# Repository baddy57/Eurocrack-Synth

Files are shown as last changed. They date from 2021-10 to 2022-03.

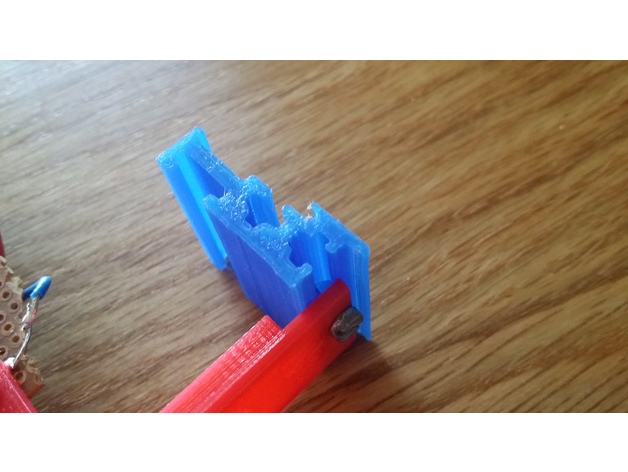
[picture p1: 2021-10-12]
3D PARTS/RACK16/trash/Parametric_Eurorack_Rail2/images/8c8c8380b167ee0547331ad15cff7e31_preview_featured.jpg

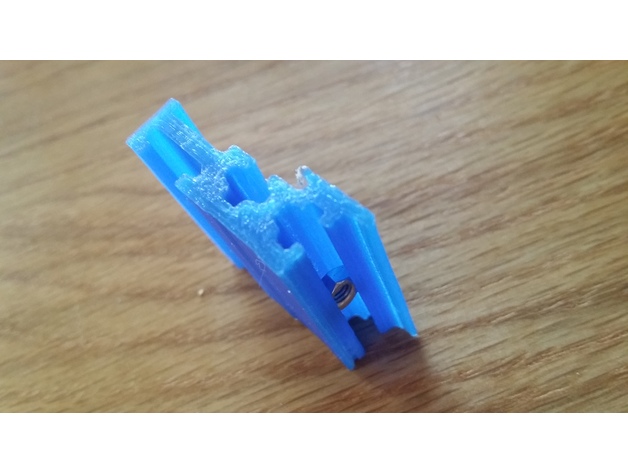
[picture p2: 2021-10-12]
3D PARTS/RACK16/trash/Parametric_Eurorack_Rail2/images/5f590f1a4b3af3753e3ca944733ad141_preview_featured.jpg

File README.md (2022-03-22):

# Eurocrack-Synth
inspired by https://github.com/mattybrad/polymod

this is my clone of an eurorack modular synthesizer.<br>
it works based on a teensy board and uses paul stoffregen's audio library and other arduino libraries

basically there are a bunch of cascaded multiplexers, which are used to get as many things as possible connected to the board.<br>
up to 4 cases can be connected with db25 cables to the main box, and each of them can have up to 16 modules connected via 16pin flat cables.<br>
each one of these 64 slots has an address, corresponding to the multiplexers selectors values used to reach them.<br>
every module has an unique id (set via dip switches) and when the teensy is turned on, it reads this id to understand which modules are connected and where.<br>
modules can have up to 8 3.5mm sockets that can send signals to other modules and up to 24 (small pcb) or 56 (big pcb) among potentiometers, switches, buttons, faders and 3.5mm sockets for receiving signals.
(the actual number of the inputs in lower because both input and outputs sockets use two pins)

any output socket can be connected to multiple inputs using 3.5mm mono jacks and splitters.<br>
the signal that flows in these cables is not an audio signal, but just a digital signal sent from the outputs, that, if received by any inputs, lets the code know that an audioconnection object must be created.

similarities to real eurorack synths:<br>
	module size, which is 128.5 x 5.08*n mm<br>    .
	m3 screws used to attach the modules to the rack<br>
	3.5mm mono jacks<br>
	fpc16 cables<br>

other features: <br>
	analog audio in/out, thanks to the teensy audio board <br>
	usb audio in/out <br>
	midi in/out <br>
	usb midi in/out <br>
	a touch screen display (used mainly for debugging purposes at the moment) <br>
	polyphony<br>
	of course, rgb leds (i still need to fix them though)

special thanks to:<br>
	Paul Stoffregen and anybody who has worked on the audio library <br>
	everyone on the pjrc forum<br>
	youtube channel notes and volts<br>
	again mattybrad for sharing his code<br>

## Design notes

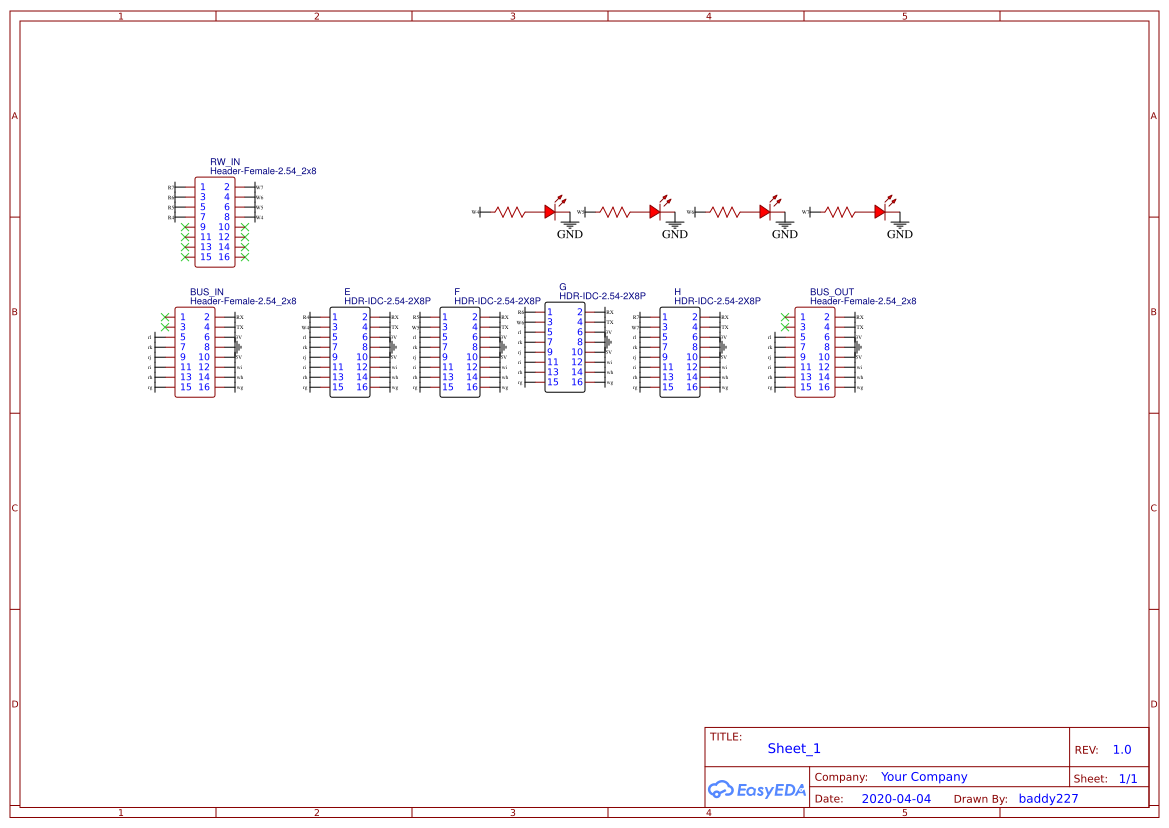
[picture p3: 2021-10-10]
PCB/Project_rack16_B_2021-10-10_22-06-08/1d647eb44f6a4349aa5675ee98e57c5a.png

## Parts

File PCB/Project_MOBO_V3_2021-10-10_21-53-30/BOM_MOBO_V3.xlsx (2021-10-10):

ID | Name | Designator | Footprint | Quantity
1 | 10uF | C1 | CAP-TH_BD5.0-P2.5-D0.5-FD | 1
2 | 1N4448 | D1 | DO-35 | 1
3 | HDR-IDC-2.54-2X8P | P1 | IDC-TH_16P-P2.54_C3406 | 1
4 | USB-B-Female-TH_C46393 | USB_B | USB-B_4PIN-FEMALE_BF90 | 1
5 | USB-AF-90-13.6X14.4-H6.95 | USB_A | USB-A-TH_C42628 | 1
6 | Header-Male-2.54_1x3 | RGB0 | HDR-TH_3P-P2.54-V | 1
7 | Female header 2.54-1*14P | T0,T1 | HDR-TH_14P-P2.54-V | 2
8 | USB_H | H3 | HDR-F-2.54_1X5 | 1
9 | HDR-IDC-2.54-2X13P | DB25_3,DB25_1,DB25_2,DB25_0 | HDR-IDC-2.54-2X13P | 4
10 | LED-TH-3mm_R | LED1 | LED-TH_BD3.0_RED | 1
11 | 6N138 | 6N138 | DIP-8_L9.8-W6.6-P2.54-LS7.6-BL | 1
12 | 47 | R3,R2 | AXIAL-0.3 | 2
13 | 220 | R1 | AXIAL-0.3 | 1
14 | 4051 | WRITE,READ | DIP-16_L20.0-W6.4-P2.54-LS7.6-BL | 2
15 | 1k | R4 | R_AXIAL-0.3 | 1
16 | 100 | R6 | R_AXIAL-0.3 | 1
17 | 220S-1*4P H=8.5MM Ytype Gold-plated | H8 | DIP-1X4P2.54 | 1
18 | Header-Male-2.54_1x2 | FAN_0,PWR_SW,FAN_1 | HDR-2X1/2.54 | 3
19 | MIDI_CONN_FEMALE | MIDI_IN,MIDI_OUT | DIN_5_FEMALE | 2
20 | rgb shifter | U1 | 4 CHANNEL LOGIC LEVEL SHIFTER BSS138 | 1
21 | HDR-F-2.54_1x10 | H1,H2 | HDR-F-2.54_1X10 | 2

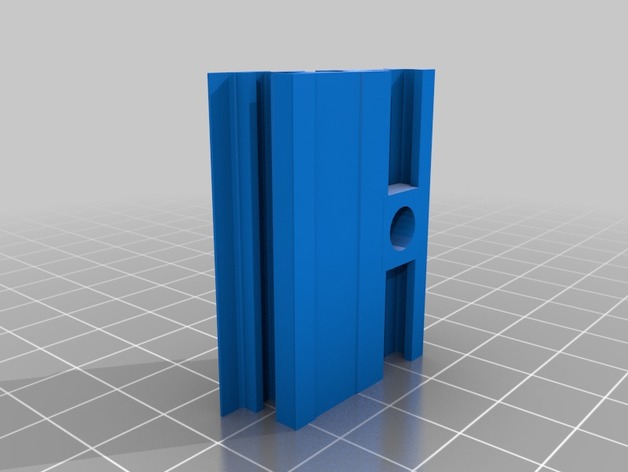
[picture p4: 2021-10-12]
3D PARTS/RACK16/trash/Parametric_Eurorack_Rail2/images/b696e86ae9955fa916dbfd1d7d6db6de_preview_featured.jpg

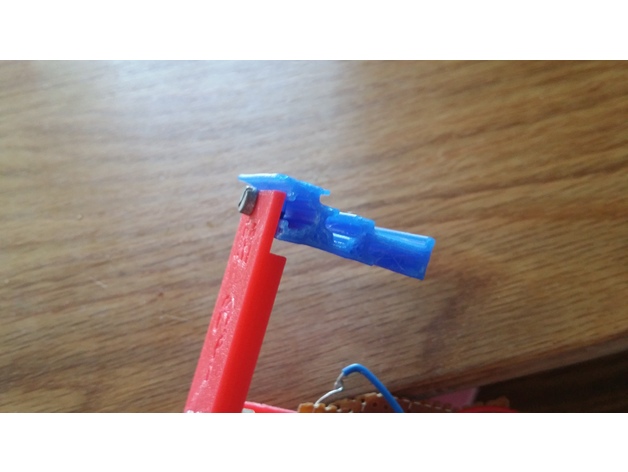
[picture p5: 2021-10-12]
3D PARTS/RACK16/trash/Parametric_Eurorack_Rail2/images/6418ca7d0646d6a987d5e6632119a3b7_preview_featured.jpg

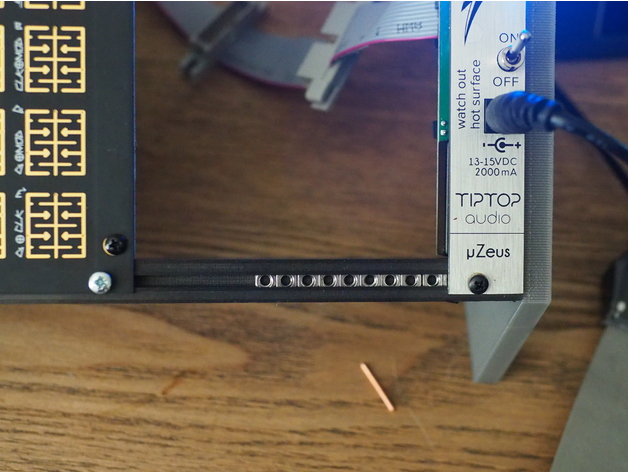
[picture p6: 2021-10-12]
3D PARTS/RACK16/trash/Parametric_Eurorack_Rail/images/79c224f203232b801c12202c8b1ffca3_preview_featured.JPG

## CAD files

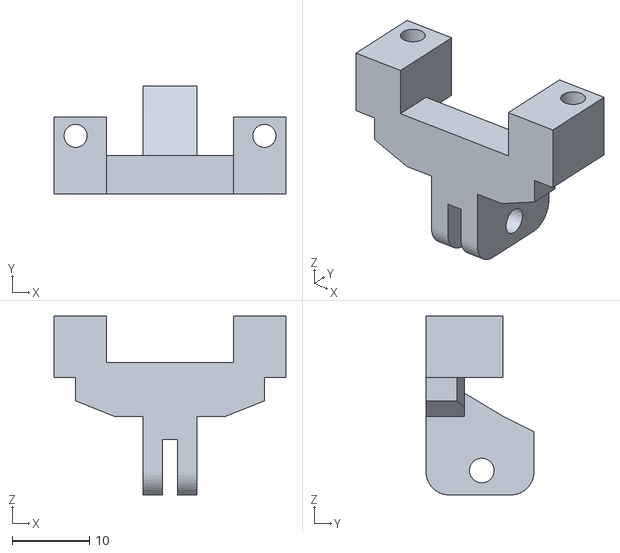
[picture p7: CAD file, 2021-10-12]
3D PARTS/MODULES/VCF_PCB_V3.stl
30.1 x 14.0 x 23.2

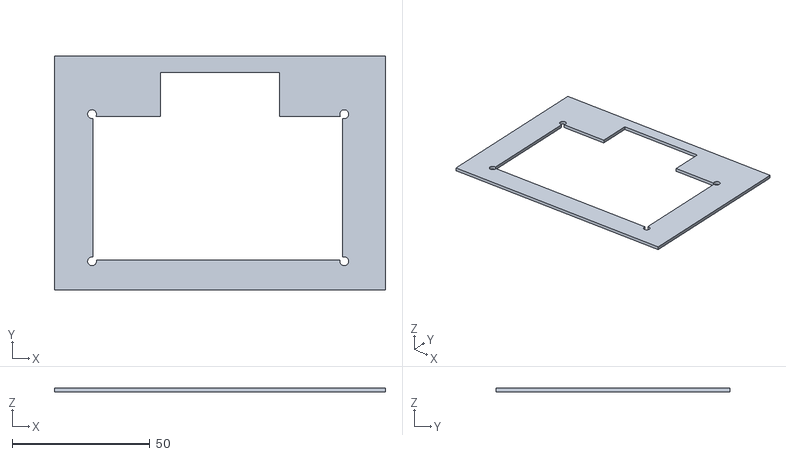
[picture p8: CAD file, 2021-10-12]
3D PARTS/RACK16/SHIELD_v3_internal.stl
120.0 x 85.0 x 1.50

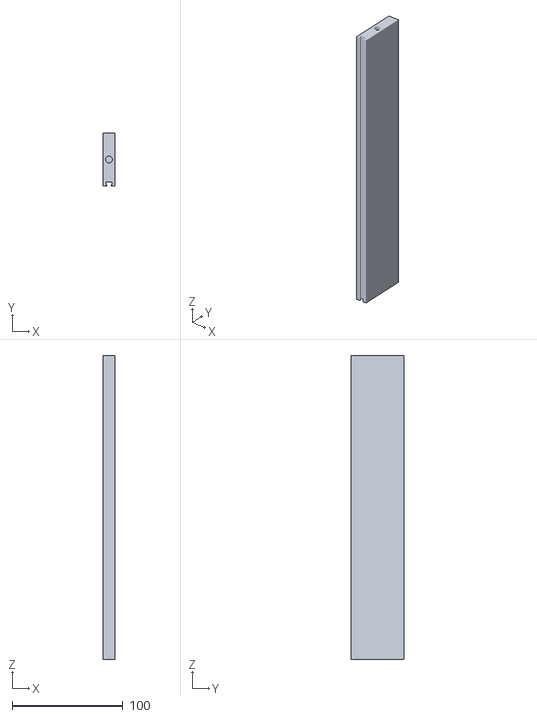
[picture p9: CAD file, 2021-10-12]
3D PARTS/RACK16/trash/Parametric_Eurorack_Rail/files/EurorackRail_54hp.stl
11.0 x 47.6 x 274.3

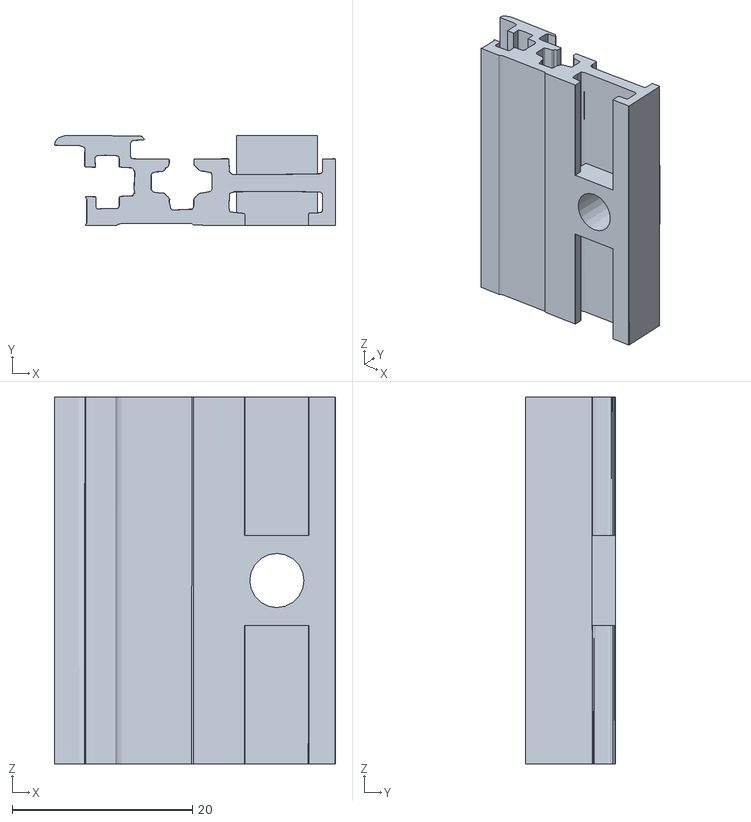
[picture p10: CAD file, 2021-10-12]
3D PARTS/RACK16/trash/Parametric_Eurorack_Rail2/files/Eurorack_Rail_8HP_with_holes.stl
31.2 x 10.0 x 40.7

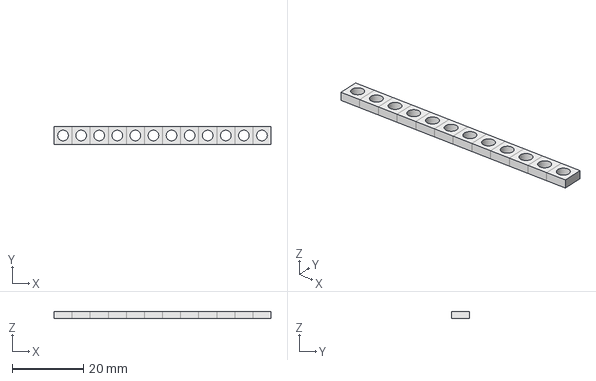
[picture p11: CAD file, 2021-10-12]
3D PARTS/RACK16/trash/strip 12 print x12.FCStd
61.0 x 5.08 x 2.00 mm

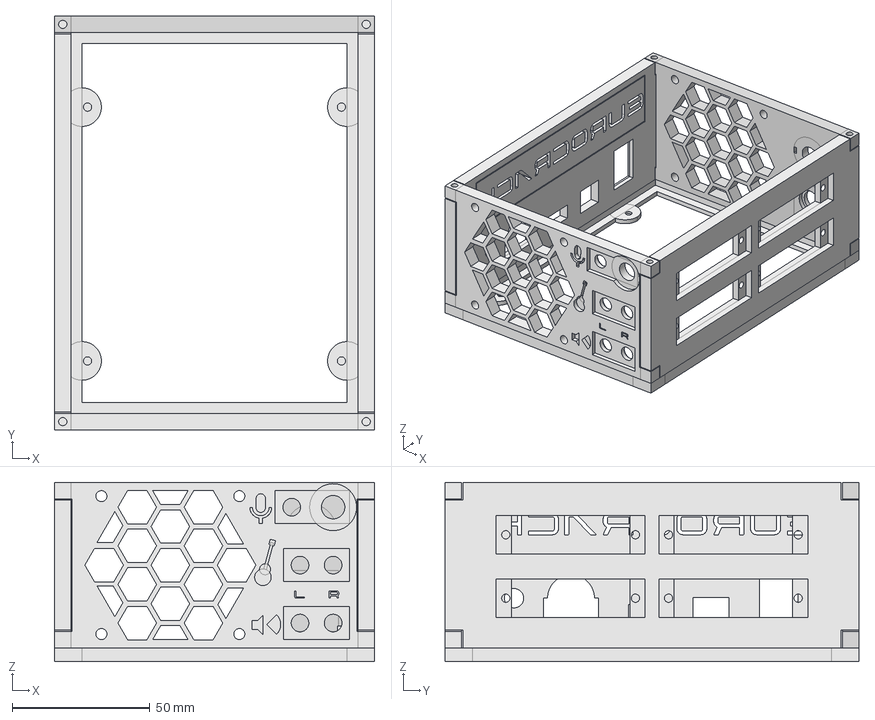
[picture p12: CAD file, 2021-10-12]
3D PARTS/MASTER BOX/MASTER BOX.FCStd
116.0 x 150.0 x 65.0 mm
BOTTOM
LOGO

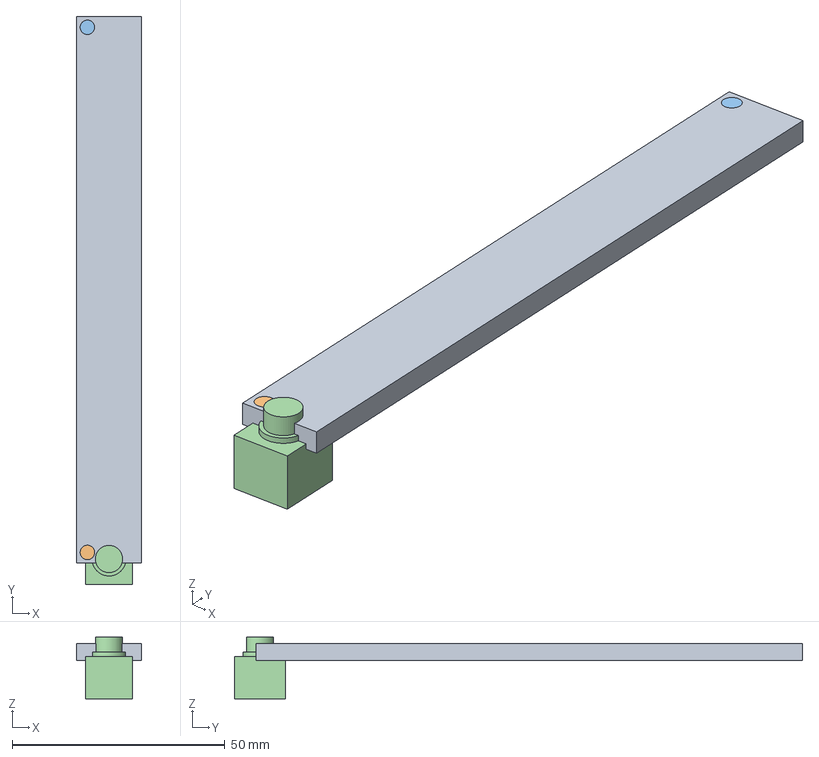
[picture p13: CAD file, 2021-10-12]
3D PARTS/MODULES/HP_AUDIOOUT.FCStd
15.2 x 133.5 x 14.5 mm
M3 SCREW
M3 SCREW001
3.5 jack

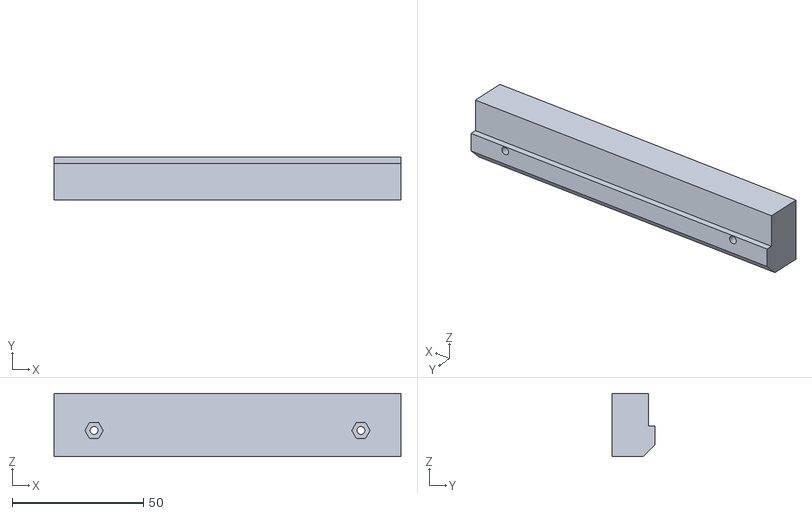
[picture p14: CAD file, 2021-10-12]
3D PARTS/RACK16/RGB_EPOXY.stl
132.1 x 16.5 x 24.0

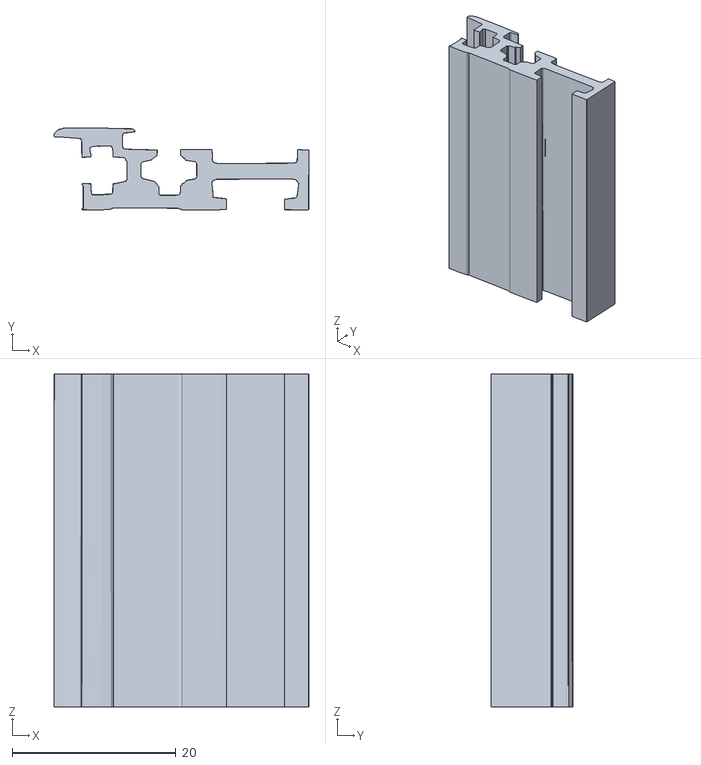
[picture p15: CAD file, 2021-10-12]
3D PARTS/RACK16/trash/Parametric_Eurorack_Rail2/files/Eurorack_Rail_8HP_Gie_Tec.stl
31.1 x 10.0 x 40.6

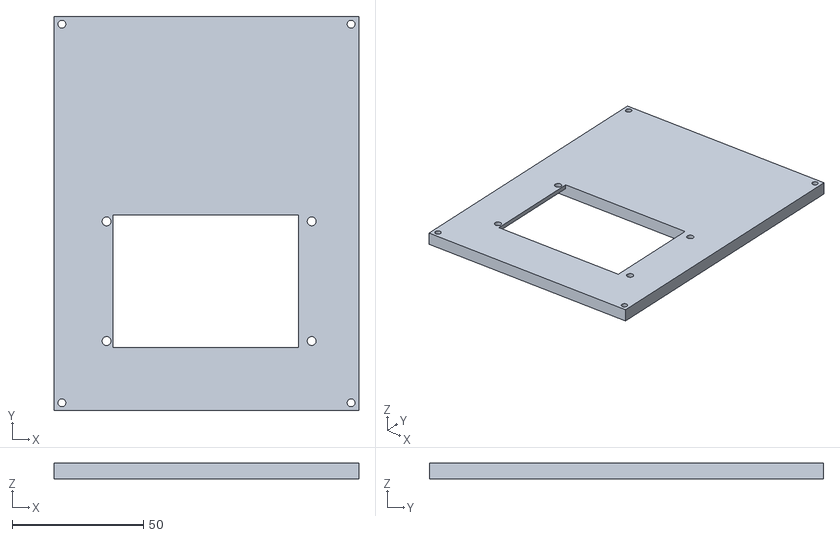
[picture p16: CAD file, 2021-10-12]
3D PARTS/MASTER BOX/MASTER_TOP.stl
116.0 x 150.0 x 6.00

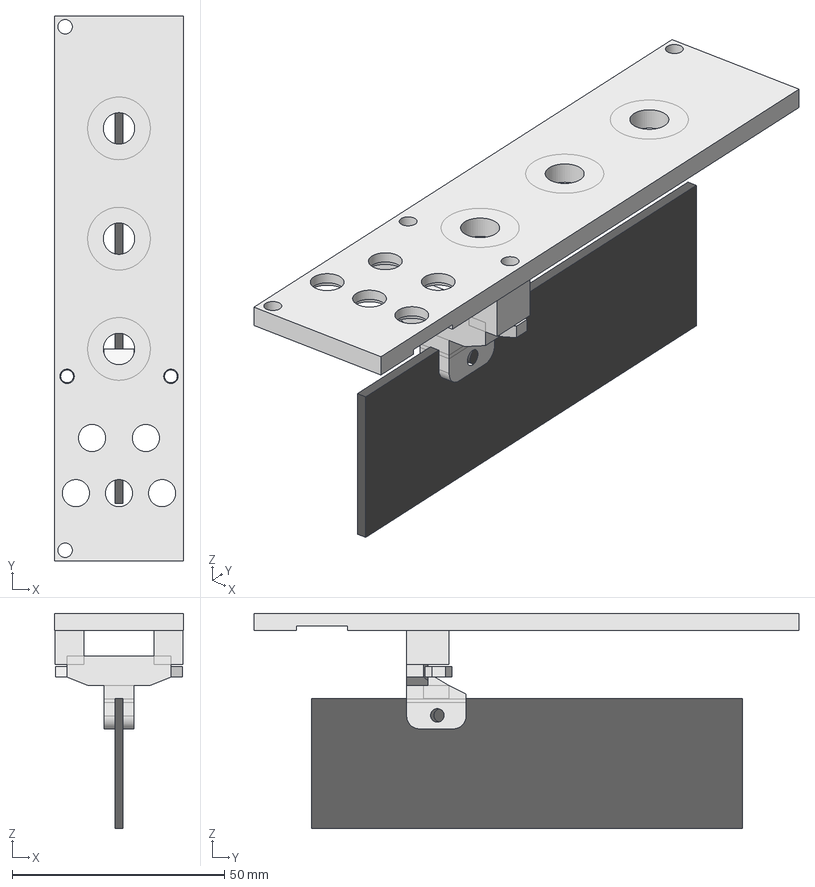
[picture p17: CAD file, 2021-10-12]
3D PARTS/MODULES/6HP_VCF.FCStd
30.5 x 128.5 x 50.7 mm
pcb001
hex_nut
hex_nut001
PCB MOUNT

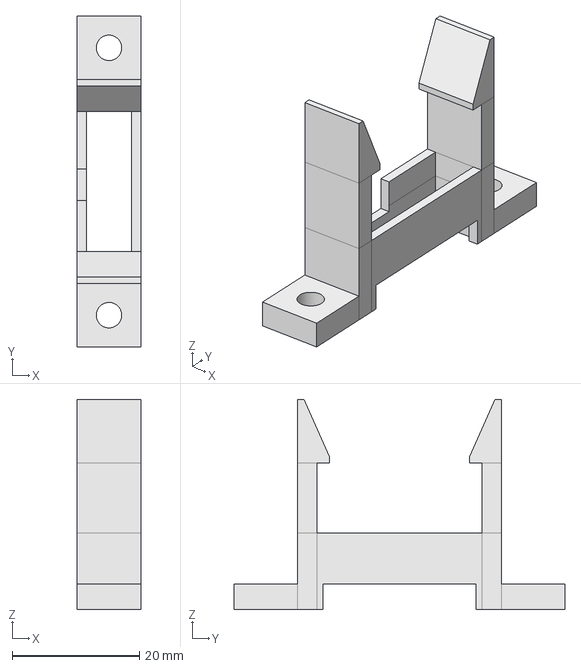
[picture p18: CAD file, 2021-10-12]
3D PARTS/RACK16/trash/IDC 16 MOUNT.FCStd
10.0 x 52.0 x 33.0 mm

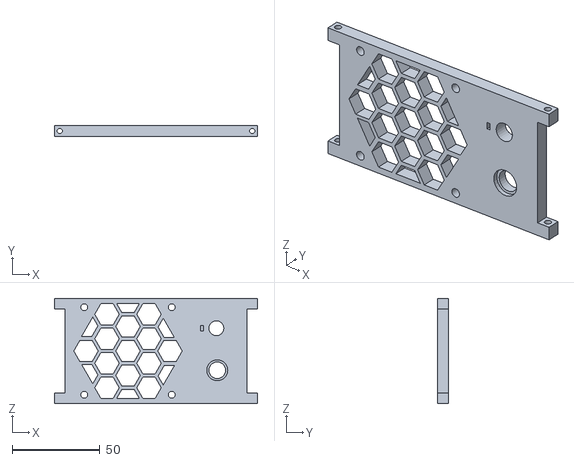
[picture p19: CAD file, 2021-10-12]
3D PARTS/MASTER BOX/MASTER_AUDIO_FRONT_PANEL.stl
116.0 x 6.00 x 60.0

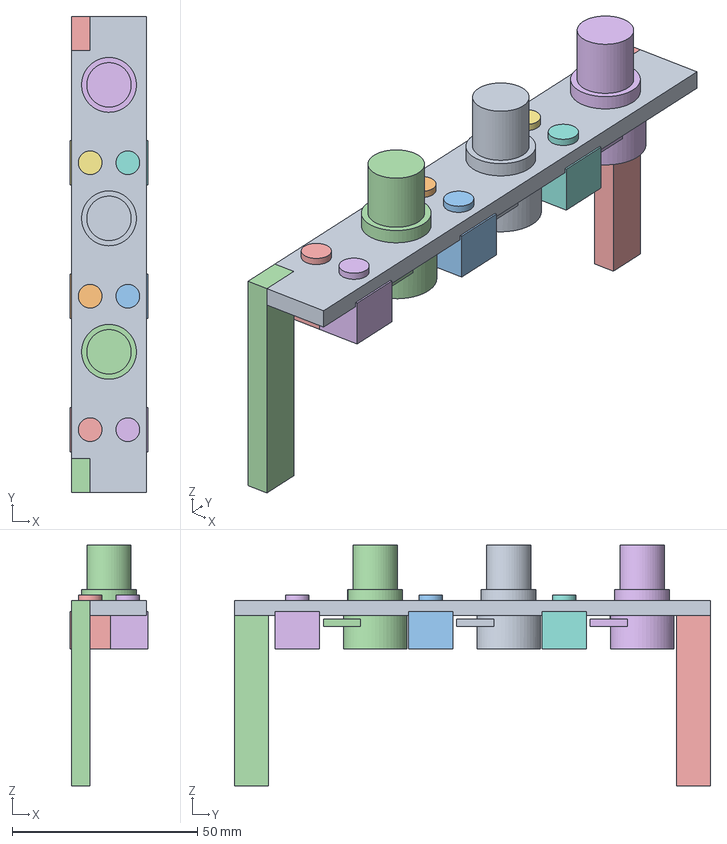
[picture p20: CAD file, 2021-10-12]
3D PARTS/MODULES/4HP_MIXER3_cv.FCStd
21.2 x 128.5 x 65.0 mm
M3 SCREW
M3 SCREW001
POTENTIOMETER
3.5 jack
3.5 jack001
POTENTIOMETER001
3.5 jack002
3.5 jack003
POTENTIOMETER002
3.5 jack004
3.5 jack005

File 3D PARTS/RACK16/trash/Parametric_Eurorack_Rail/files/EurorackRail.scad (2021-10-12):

railHp = 54;//the length of a rail in hp
hp = 5.08;//represents of the width in mm of each unit of hp; defaults to Eurorack standard (5.08)

slidingNutHeight = 5.4; //the height of the nut; defaults to the height of a common m3 square nut (5.4)

slidingNutThickness = 2.4; //The thickness/depth of the nut, back to front; defaults to the size of a common m3 square nut (2.4)

slidingNutMargin = .2;//margin added to the thickness of the nut for fit tolerance

railGapHeight = 3.4;//The gap in the rail through which the nuts are visible

railFrontThickness = 2.25; //The thickness of the part of the rail between the front of the rail and the nuts

railBackThickness = 45;//The thickness of the rail "behind" the nuts; thicker is presumably sturdier and less prone to bending; should be thick enough to accommodate more than 2x bracketNutHeight
railHeight = 11;//The overall height of the rail, "top" to "bottom"; should be considerably greater than the bracket nut height

railMargin = 0;//A little extra length to each side of the rail, as needed

bracketNutHeight = 9.8; //The height of the nut securing the rail to the bracket; defaults to common m6 square nut (9.8)
bracketNutThickness = 4.6;//The thickness of the bracket nut; defaults to a common m6 square nut (4.6)
bracketNutInset = 8; //How "deep" into the rail is the nut inset; longer screws will require a greater value
bracketNutMargin =.35;//A margin around the bracket nut for fit tolerance; This nut ought to fit fairly snugly
bracketScrewHoleDiameter = 6.1; //The diameter of the bracket screw; defaults to typical m6 diameter (6.1)

railDepth = railFrontThickness+slidingNutMargin*2+railBackThickness;
railLength = railHp*hp+railMargin*2;

echo("rail depth: ", railDepth);
echo("rail length: ", railLength);

rail();

module rail()
{
    difference()
    {
        railBase();
        translate([railHeight/2,-1,railLength/2-.5]){
            railDiff();
        }   
        
        translate([railHeight/2,railDepth/2,railLength - (bracketNutInset+((bracketNutThickness+bracketNutMargin*2)/2))]){
     bracketNutDiff();
        }
        

translate([railHeight/2,railDepth/2,(bracketNutInset+((bracketNutThickness+bracketNutMargin*2)/2))]){
    rotate([180,0,0]){
     bracketNutDiff();
    }
        }
    }
}

module railBase()
{
    cube([railHeight,railDepth,railLength]);
}

module bracketNutDiff()
{
    bracketNutNotchDepth = (bracketNutHeight+bracketNutMargin*2) - (railHeight -(bracketNutHeight+bracketNutMargin*2));
    
    bracketScrewRad = bracketScrewHoleDiameter/2;
    
    union(){
    cube([bracketNutHeight+bracketNutMargin*2, bracketNutHeight+bracketNutMargin*2, bracketNutThickness+bracketNutMargin*2], center = true);
        translate([0,0,bracketNutThickness/2-20]){
            cylinder(r=bracketScrewRad, h=bracketNutInset+21, $fn=20);
            }
            translate([-((bracketNutHeight+bracketNutMargin*2)+bracketNutNotchDepth)/2-.5,0,0]){
                cube([bracketNutNotchDepth+1,bracketNutHeight+bracketNutMargin*2, bracketNutThickness+bracketNutMargin*2], center=true);
                }
    }
}

module railDiff()
{
    union()
    {
        cube([railGapHeight,railFrontThickness+2,railLength+2], center=true);
        translate([0,railFrontThickness+1,0]){
        cube([slidingNutHeight+slidingNutMargin*2,slidingNutThickness+slidingNutMargin*2,railLength+2],center=true);
        }
    }
}

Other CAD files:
3D PARTS/RACK16/trash/rail buona senza strip 2 meglio.FCStd
3D PARTS/RACK16/RGB_EPOXY_v5_negativo.stl
3D PARTS/RACK16/trash/STRIP 12HP.stl
3D PARTS/MASTER BOX/MASTER_AUDIO_IO_PANEL_V2.stl
3D PARTS/LEGACY RACK 7U.FCStd
3D PARTS/MASTER BOX/MASTER BOX_v2.FCStd
3D PARTS/MASTER BOX/MASTER BOX_v3.FCStd
3D PARTS/MASTER BOX/MASTER_AUDIO_FRONT_PANEL_V2.stl
3D PARTS/MASTER BOX/MASTER_AUDIO_IO_PANEL.stl
3D PARTS/MASTER BOX/MASTER_BACK_PANEL_V2.stl
3D PARTS/MASTER BOX/MASTER_BOTTOM.stl
3D PARTS/MASTER BOX/MASTER_DB25_PANEL.stl
3D PARTS/MASTER BOX/MASTER_IO_PANEL_V3.stl
3D PARTS/MASTER BOX/MASTER_MIDI_PANEL.stl
3D PARTS/MASTER BOX/MASTER_MIDI_PANEL_V2.stl
3D PARTS/MODULES/20HP_MIXER8.FCStd
3D PARTS/MODULES/20HP_MIXER8.stl
3D PARTS/MODULES/2HP_AUDIOOUT.FCStd
3D PARTS/MODULES/2HP_AUDIOOUT.stl
3D PARTS/MODULES/2HP_PCB.stl
3D PARTS/MODULES/3HP_AUDIOOUT.FCStd
3D PARTS/MODULES/3HP_AUDIOOUT.stl
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

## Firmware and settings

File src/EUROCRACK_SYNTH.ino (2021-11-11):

/*
 Name:		EUROCRACK_SYNTH.ino
 Created:	10/10/2021 11:05:07 PM
 Author:	cristian
*/

//#include libraries
#include <vector>
#include <Audio.h>
#include <SD.h>
#include <SPI.h>

//include my classes
#include "Module.h"
#include "Address.h"
#include "PatchCable.h"
#include "HardwareCfg.h"
#include "ModuleFactory.h"

//constants
extern const uint_fast8_t HIGH_UPDATE_PRIORITY;
extern const uint_fast8_t MEDIUM_UPDATE_PRIORITY;
extern const uint_fast8_t LOW_UPDATE_PRIORITY;
extern const uint_fast8_t READ_PIN;
extern const uint_fast8_t WRITE_PIN;

//AudioControlSGTL5000     sgtl5000_1;

//global variables
std::vector<Module*> activeModules;
ILI9341_t3 tft = ILI9341_t3(TFT_CS, TFT_DC);

USBHost myusb;
MIDIDevice midi1(myusb);


// #include <Adafruit_NeoPixel.h>
// Adafruit_NeoPixel strip = Adafruit_NeoPixel(57, pins::RGB1_3, NEO_GRB + NEO_KHZ800);
#define POLYPHONIC



void setup() {

	pinMode(pins::RA, OUTPUT);
	pinMode(pins::RB, OUTPUT);
	pinMode(pins::RC, OUTPUT);
	pinMode(pins::RD, OUTPUT);
	pinMode(pins::RE, OUTPUT);
	pinMode(pins::RF, OUTPUT);
	pinMode(pins::RG, OUTPUT);
	pinMode(pins::RH, OUTPUT);
	pinMode(pins::RI, OUTPUT);
	pinMode(pins::RJ, OUTPUT);
	pinMode(pins::RK, OUTPUT);
	pinMode(pins::RL, OUTPUT);
	pinMode(pins::WA, OUTPUT);
	pinMode(pins::WB, OUTPUT);
	pinMode(pins::WC, OUTPUT);
	pinMode(pins::WD, OUTPUT);
	pinMode(pins::WE, OUTPUT);
	pinMode(pins::WF, OUTPUT);
	pinMode(pins::WG, OUTPUT);
	pinMode(pins::WH, OUTPUT);
	pinMode(pins::WI, OUTPUT);
	pinMode(pins::WRITE, OUTPUT);
	pinMode(pins::READ, INPUT);
	pinMode(pins::VOLUME, INPUT);
	pinMode(pins::RGB1_3, OUTPUT);
	pinMode(pins::RGB0_3, OUTPUT);

	AudioMemory(1500);
	delay(2000);

	tft.begin();
	tft.setRotation(4);
	tft.fillScreen(ILI9341_BLUE);

	myusb.begin();


	module::factory(activeModules);

	SD.begin(BUILTIN_SDCARD);
	Serial.println("sd started");


	// strip.begin();
	// strip.setBrightness(255);
	// strip.show(); // Initialize all pixels to 'off'

	  // rainbow(5);


}

void loop() {
	//update Modules
	for (auto i = activeModules.begin(),
		end = activeModules.end();
		i < end; ++i) {
		(*i)->updateValues();
	}
	Module::updateConnections();
	
}












/*







void rainbow(uint8_t wait) {
  uint16_t i, j;

  for(j=0; j<256; j++) {
	for(i=0; i<strip.numPixels(); i++) {
	  strip.setPixelColor(i, Wheel((i+j) & 255));
	}
	strip.show();
	delay(wait);
  }
}

// Slightly different, this makes the rainbow equally distributed throughout
void rainbowCycle(uint8_t wait) {
  uint16_t i, j;

  for(j=0; j<256*5; j++) { // 5 cycles of all colors on wheel
	for(i=0; i< strip.numPixels(); i++) {
	  strip.setPixelColor(i, Wheel(((i * 256 / strip.numPixels()) + j) & 255));
	}
	strip.show();
	delay(wait);
  }
}
// Input a value 0 to 255 to get a color value.
// The colours are a transition r - g - b - back to r.
uint32_t Wheel(byte WheelPos) {
  WheelPos = 255 - WheelPos;
  if(WheelPos < 85) {
	return strip.Color(255 - WheelPos * 3, 0, WheelPos * 3);
  }
  if(WheelPos < 170) {
	WheelPos -= 85;
	return strip.Color(0, WheelPos * 3, 255 - WheelPos * 3);
  }
  WheelPos -= 170;
  return strip.Color(WheelPos * 3, 255 - WheelPos * 3, 0);
}
 */

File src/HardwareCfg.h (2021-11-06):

#ifndef __HARDWARE_CFG_H__
#define __HARDWARE_CFG_H__ 


#define FIX_BIG_MODULE_PIN(x) 


#include <cstdint>
#include <ILI9341_t3.h>
//#include <font_Arial.h> // from ILI9341_t3
#include <XPT2046_Touchscreen.h>
#include <SPI.h>
#include "USBHost_t36.h"
//PINS
namespace pins {
	enum {
		RX, 
		TX, 
		WD, 
		WE, 
		WF, 
		LCD_DC, 
		WG, 
		T_CS=9, 
		WH, 
		__MOSI, 
		__MISO, 
		__SCK, 
		READ, 
		VOLUME, 
		__IRQ=16, 
		WC, 
		WRITE=22, 
		WA=24, 
		RGB1_3, 
		WB, 
		RGB0_3, 
		WI, 
		RL, 
		RK, 
		RJ, 
		RI, 
		RA, 
		RB, 
		RC, 
		LCD_CS, 
		RH, 
		RG, 
		RF, 
		RE, 
		RD};
};

const uint_fast8_t MIDI_OUT_PIN = 	pins::TX;
const uint_fast8_t MIDI_IN_PIN 	= 	pins::RX;


const uint_fast8_t IN_SEL[6]	= 	{pins::RC, pins::RB, pins::RA, pins::RF, pins::RE, pins::RD};	//IN SEL
const uint_fast8_t IN_SEL2[6] 	=	{pins::RG, pins::RH, pins::RI, pins::RL, pins::RK, pins::RJ};	//IN SEL2
//ok for small module (4053)

//const uint_fast8_t IN_SEL2[6] 	=	{pins::RI, pins::RH, pins::RG, pins::RL, pins::RK, pins::RJ};	//IN SEL2
//ok for big module (4051)

const uint_fast8_t OUT_SEL[6]	= 	{pins::WC, pins::WB, pins::WA, pins::WF, pins::WE, pins::WD};	//OUT SEL
const uint_fast8_t OUT_SEL2[3]	= 	{pins::WI, pins::WH, pins::WG};									//OUT SEL2



const uint_fast8_t READ_PIN 	=	pins::READ;  
const uint_fast8_t WRITE_PIN 	=	pins::WRITE;
const uint_fast8_t VOLUME_PIN 	=	pins::VOLUME;

const bool ID_MUX_LOCATION [3] = {0, 0, 0}; //IN_SEL2[0, 1, 2] --->pins::RG, pins::RH, pins::RI



#define CS_PIN pins::T_CS //14
#define TFT_DC pins::LCD_DC	//5
#define TFT_CS pins::LCD_CS	//36
// MOSI=11, MISO=12, SCK=13



#define MUX_DELAY 5
const uint_fast8_t POT_DEADZONE = 3;
const uint_fast8_t POT_READS = 5;

const uint_fast8_t MAX_MODULES = 64;


const uint_fast8_t HIGH_UPDATE_PRIORITY = 255;
const uint_fast8_t MEDIUM_UPDATE_PRIORITY = 128;
const uint_fast8_t LOW_UPDATE_PRIORITY = 1;
const uint_fast8_t POLYPHONY = 10;


//USBHost myusb;

#define TIRQ_PIN 16//pins::__IRQS
//XPT2046_Touchscreen ts(CS_PIN, TIRQ_PIN);
//XPT2046_Touchscreen ts(CS_PIN); // Param 2 - NULL - No interrupts
//XPT2046_Touchscreen ts(CS_PIN, 255); // Param 2 - 255 - No interrupts
//XPT2046_Touchscreen ts(CS_PIN, TIRQ_PIN); // Param 2 - Touch IRQ Pin - interrupt enabled polling


//fix big module address
#define fix(x)                  \
    (x)>32 && (x)%16>=8 ?       \
        (x) :                   \
    ((x>=32) ?                  \
        (x-24) :                \
    ((x%16)>=8 ?                \
        (x+24) :                \
        (x)))


#endif

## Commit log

2021-10-10 added pcb files
    [BOM_MOBO_V3.xlsx]
2021-10-12 edited C:\Program Files\Arduino\hardware\teensy\avr\libraries\Audio\utility\dspinst.h https://stackoverflow.com/questions/25579759/gcc-inline-assembly-what-does-asm-operand-has-impossible-constraints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
2021-10-12 COMPILATION OK! added 3d files
    [20HP_MIXER8.FCStd, 20HP_MIXER8.stl, 26HP.stl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]
2021-10-12 fixed outputSockets vector being =0
    [EUROCRACK_SYNTH.ino]
2021-10-14 commit before writing socket.h
2021-10-14 polymorphic socket class. solved intellisense bug (do not inheriti include dirs!)
2021-10-18 PATCH CABLES ARE WORKING
2021-11-01 fixed mixer slider bug
    [EUROCRACK_SYNTH.ino, HardwareCfg.h]
2021-11-06 added macro to fix big module control addresses; added module templates; added delay single tap module.
    [HardwareCfg.h]
